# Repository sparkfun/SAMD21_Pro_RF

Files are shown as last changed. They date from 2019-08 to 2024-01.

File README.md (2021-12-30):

SparkFun Pro RF - LoRa, 915MHz (SAMD21)
======================================

SparkFun Pro RF - LoRa, 915MHz (SAMD21) (https://www.sparkfun.com/products/14916)

[*SparkFun SAMD21 Pro RF LoRa 915MHz (WRL-14916)*](https://www.sparkfun.com/products/14916)

The [SparkFun SAMD21 Pro RF](https://www.sparkfun.com/products/14916) is the fated meeting of a SAMD21 and a long-range [RFM95W LoRa®-enabled radio](https://cdn.sparkfun.com/assets/a/9/6/1/0/RFM95W-V2.0.pdf). The outcome is a compact, blazing fast MCU with excellent point to point data transmission in the 915MHz ISM band with LoRa Capabilities. The SAMD21 Pro RF comes with a LiPo connector, an on-board LiPo charger, and a slide switch to power the board on and off. The board programs over a reinforced Micro-B connector with a slim reset button that fits nicely on the side of the board. We’ve even added our popular [Qwiic](https://www.sparkfun.com/qwiic) connector to the edge of the board making it incredibly easy to add sensors and actuators without the need for solder or a soldering iron!

Repository Contents
-------------------

* **/Hardware** - Eagle design files (.brd, .sch)
* **/Production** - Production panel files (.brd)

Documentation
--------------
* **[Hookup Guide](https://learn.sparkfun.com/tutorials/sparkfun-samd21-pro-rf-hookup-guide)** - Basic hookup guide the SAMD21 Pro RF going over the point to point radio capabilities of the radio module and how to set up and use LoRaWAN. 
* **[Arduino Example Code](https://github.com/sparkfun/Sparkfun_SAMD21_Pro_RF_Arduino_Examples)** - Code for the radio module including point to point and LoRaWAN examples.
* **[SAMD21G18A-AU Datasheet](https://cdn.sparkfun.com/datasheets/Dev/Arduino/Boards/Atmel-42181-SAM-D21_Datasheet.pdf)** - Datasheet for the SAMD21G
* **[HopeRF RFM95W Radio Module](https://cdn.sparkfun.com/assets/a/9/6/1/0/RFM95W-V2.0.pdf)** - Datasheet for the RFM95W radio module.

License Information
-------------------

This product is _**open source**_! 

Please review the LICENSE.md file for license information. 

If you have any questions or concerns on licensing, please contact techsupport@sparkfun.com.

Distributed as-is; no warranty is given.

- Your friends at SparkFun.

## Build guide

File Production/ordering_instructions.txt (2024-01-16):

panel size, 159x107mm
PCB thickness, 0.8mm
number of layers, 2
soldermask color, Red
silkscreen color, White
oz copper, 1oz
finish, HASL lead free
stencils, top+bottom
pcs per panel, 9
min trace width, 0.1524mm / 0.0060in
min drill size, 0.3048mm / 0.0120in

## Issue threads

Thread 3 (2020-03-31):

Problem with reset

johnhulth, 2020-03-31:
I have problem with the reset and on/off button. Running the blink example. After uploading the code it runs fine, but if i push reset or switch off and on, the code will not run... no blinking!

Any ideas why I experience this behavior?

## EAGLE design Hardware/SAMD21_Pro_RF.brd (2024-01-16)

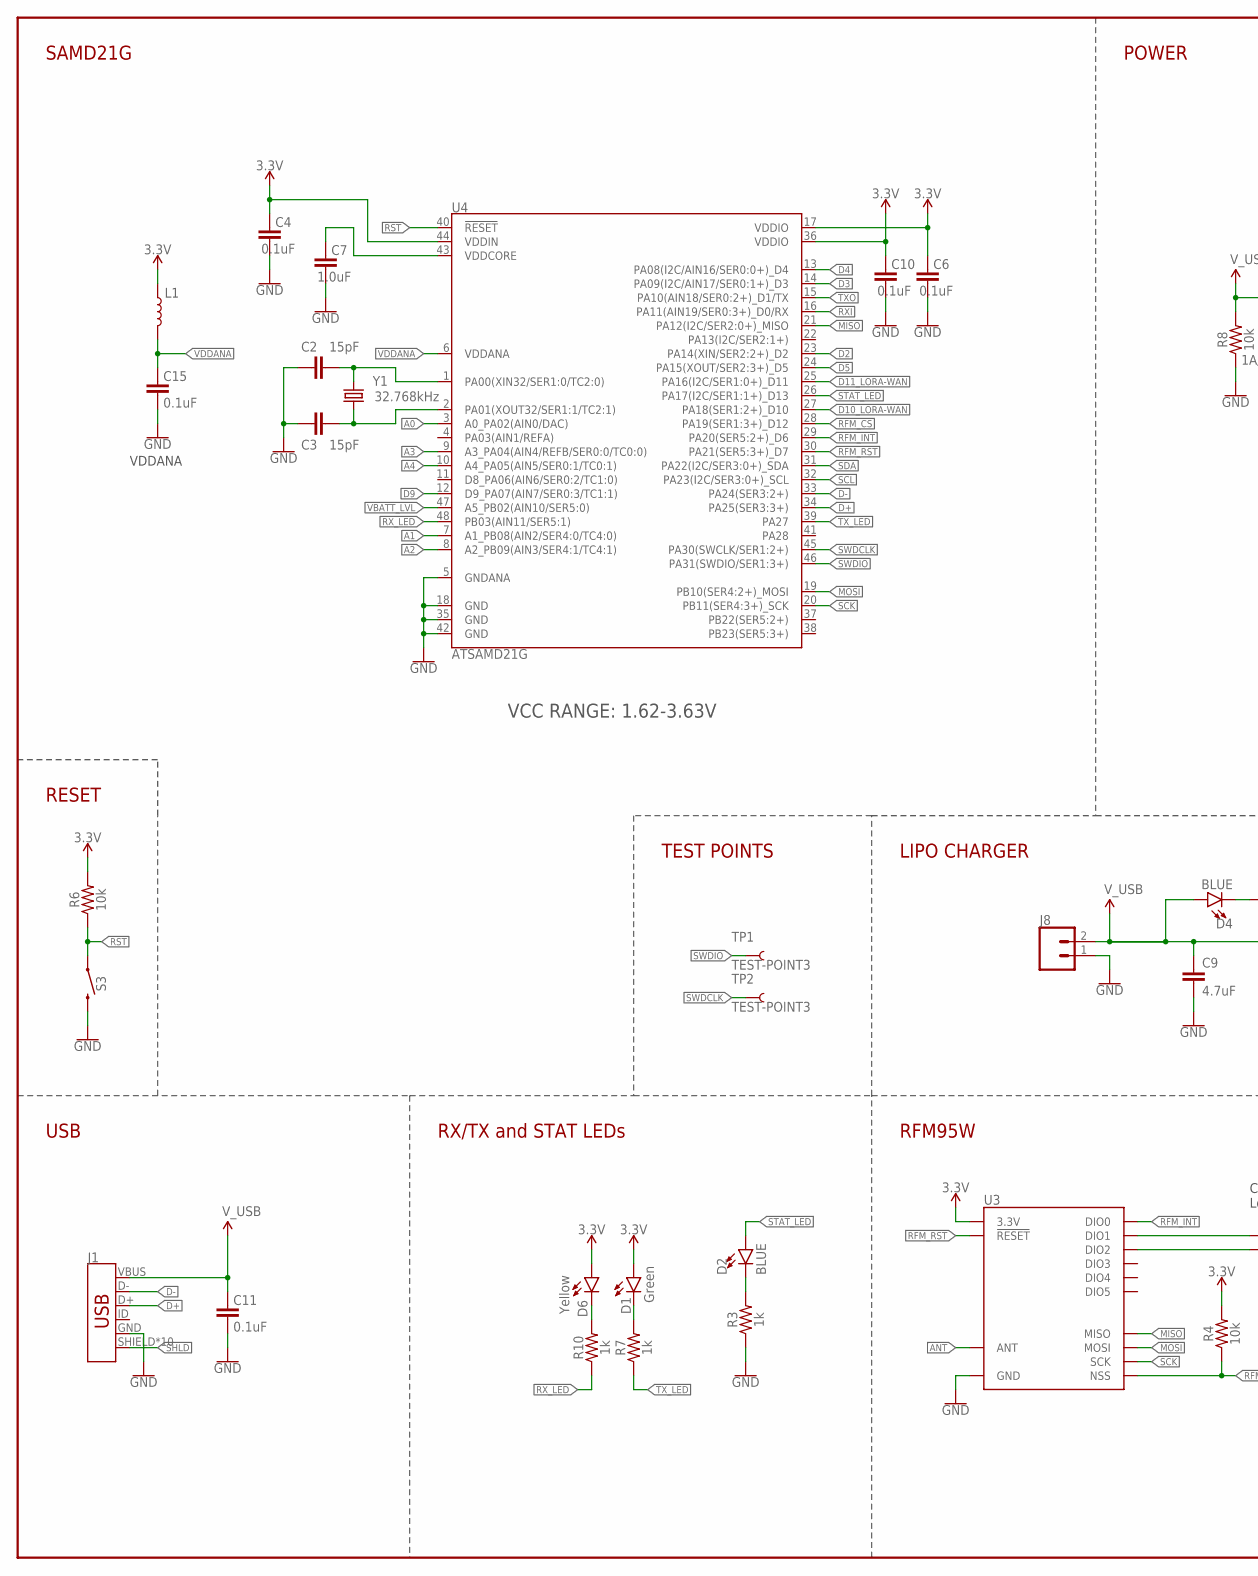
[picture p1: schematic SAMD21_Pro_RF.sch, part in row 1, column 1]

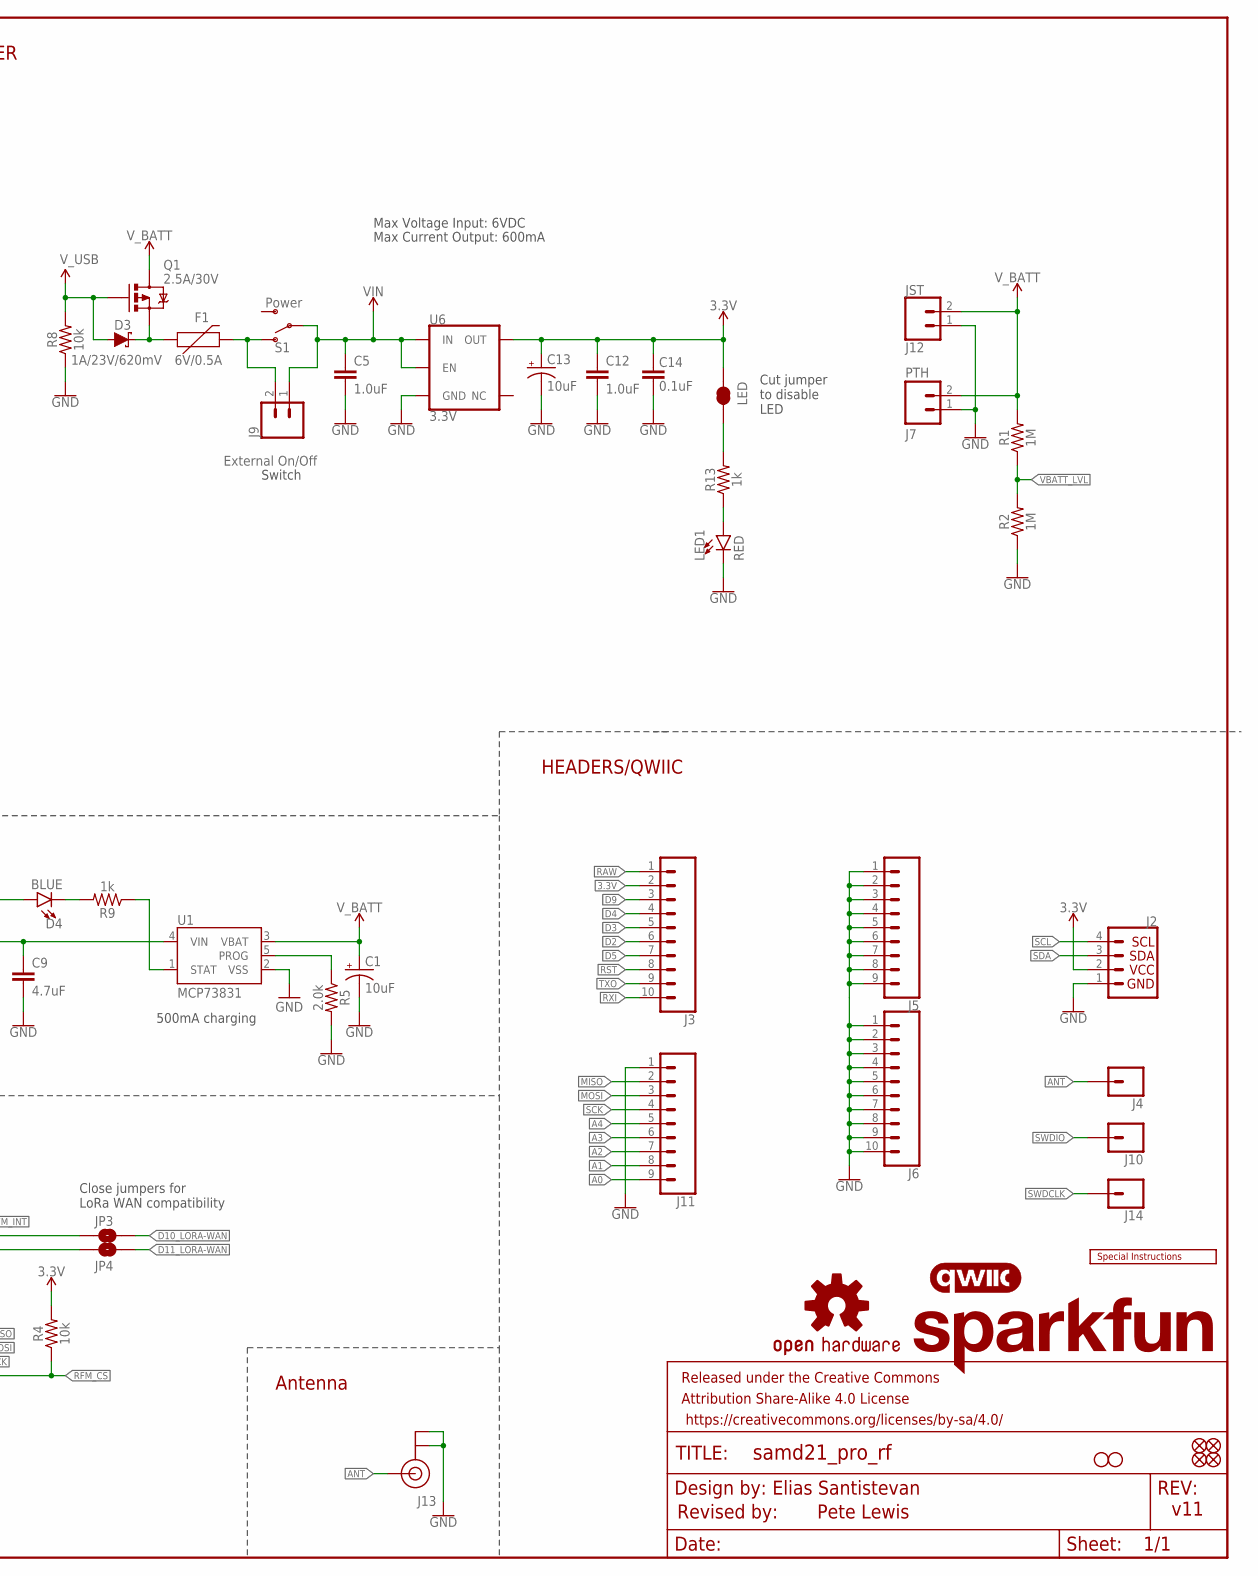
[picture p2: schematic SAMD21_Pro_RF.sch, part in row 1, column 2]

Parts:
C1, C13: 10uF; EIA3216
C2, C3: 15pF; 0603
C4, C6, C10, C11, C14, C15: 0.1uF; 0603
C5, C7, C12: 1.0uF; 0603
C9: 4.7uF; 0603
D1: Green; LED-0603
D2, D4: BLUE; LED-0603
D3: 1A/23V/620mV; SOD-323
D6: Yellow; LED-0603
F1: 6V/0.5A; 1206
FD1, FD2, FD3, FD4: FIDUCIAL1X2; FIDUCIAL-1X2
FRAME2: FRAME-LEDGER; CREATIVE_COMMONS
H1, H2: STAND-OFFTIGHT; STAND-OFF-TIGHT
J1: USB_MICRO-B_HALF_PTH_MILL; USB-MICROB-PTH-MILL
J2: QWIIC_CONNECTORJS-1MM; 1X04_1MM_RA
J3, J6: CONN_10NO_SILK_PTH_FEMALE; 1X10_NO_SILK
J4, J10, J14: CONN_01PTH_NO_SILK_YES_STOP; 1X01_NO_SILK
J5, J11: CONN_09NO_SILK; 1X09_NO_SILK
J7: PTH; 1X02_NO_SILK
J8: CONN_021X02_NO_SILK; 1X02_NO_SILK
J9: External On/Off; 1X02_NO_SILK
J12: JST; JST-2-SMD
J13: U.FL
JP3, JP4: JUMPER-SMT_2_NO_SILK; SMT-JUMPER_2_NO_SILK
L1: INDUCTORFB-30OHM; 0603
LED: JUMPER-SMT_2_NC_TRACE_SILK; SMT-JUMPER_2_NC_TRACE_SILK
LED1: RED; LED-0603
LOGO1: OSHW-LOGOMINI; OSHW-LOGO-MINI
LOGO2: SFE_LOGO_NAME.1_INCH; SFE_LOGO_NAME_.1
LOGO3: QWIIC_LOGO_5MM; QWIIC_5MM
Q1: 2.5A/30V; SOT23-3@1
R1, R2: 1M; 0603
R3, R7, R9, R10, R13: 1k; 0603
R4, R6, R8: 10k; 0603
R5: 2.0k; 0603
S1: Power; SWITCH_SPST_SMD_A
S3: MOMENTARY-SWITCH-SPST-SMD-RIGHT-ANGLE; TACTILE_SWITCH_SMD_RIGHT_ANGLE
TP1, TP2: TEST-POINT3; PAD.03X.03
U1: MCP73831; SOT23-5
U3: RFM95W; RFM95/96/97/98W
U4: ATSAMD21G; QFN-48_NO_EXPOSED_PAD
U6: 3.3V; SOT23-5
U$26: SPECIAL_INSTRUCTIONS-ORDERING; ORDERING_INSTRUCTIONS
Y1: 32.768kHz; CRYSTAL-SMD-3.2X1.5MM

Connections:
3.3V: C4.2, C6.2, C10.2, C12.1, C13.+, C14.2, D1.A, D6.A, J2.2, J3.2, L1.1, LED.1, R4.2, R6.2, U3.3.3V, U4.17 (VDDIO), U4.36 (VDDIO), U4.44 (VDDIN), U6.5 (OUT)
!RFM_CS: R4.1, U3.NSS, U4.28 (PA19(SER1:3+)_D12)
!RFM_RST: U3.!RESET, U4.30 (PA21(SER5:3+)_D7)
!RST: J3.8, R6.1, S3.1, U4.40 (!RESET!)
A0: J11.9, U4.3 (A0_PA02(AIN0/DAC))
A1: J11.8, U4.7 (A1_PB08(AIN2/SER4:0/TC4:0))
A2: J11.7, U4.8 (A2_PB09(AIN3/SER4:1/TC4:1))
A3: J11.6, U4.9 (A3_PA04(AIN4/REFB/SER0:0/TC0:0))
A4: J11.5, U4.10 (A4_PA05(AIN5/SER0:1/TC0:1))
ANT: J4.1, J13.FEED (SIGNAL), U3.ANT
CHARGE_STAT: R9.1, U1.1 (STAT)
D2: J3.6, U4.23 (PA14(XIN/SER2:2+)_D2)
D3: J3.5, U4.14 (PA09(I2C/AIN17/SER0:1+)_D3)
D4: J3.4, U4.13 (PA08(I2C/AIN16/SER0:0+)_D4)
D5: J3.7, U4.24 (PA15(XOUT/SER2:3+)_D5)
D9: J3.3, U4.12 (D9_PA07(AIN7/SER0:3/TC1:1))
D10_LORA-WAN: JP3.2, U4.27 (PA18(SER1:2+)_D10)
D11_LORA-WAN: JP4.2, U4.25 (PA16(I2C/SER1:0+)_D11)
D+: J1.D+, U4.34 (PA25(SER3:3+))
D-: J1.D-, U4.33 (PA24(SER3:2+))
GND: C1.-, C2.1, C3.1, C4.1, C5.2, C6.1, C7.1, C9.2, C10.1, C11.1, C12.2, C13.-, C14.1, C15.1, J1.GND, J2.1, J5.1, J5.2, J5.3, J5.4, J5.5, J5.6, J5.7, J5.8, J5.9, J6.1, J6.2, J6.3, J6.4, J6.5, J6.6, J6.7, J6.8, J6.9, J6.10, J7.1, J8.1, J11.1, J12.1 (2), J13.1 (GND), J13.2 (GND), LED1.C, R2.1, R3.1, R5.2, R8.1, S3.2, U1.2 (VSS), U3.GND@1 (GND), U3.GND@2 (GND), U3.GND@3 (GND), U4.5 (GNDANA), U4.18 (GND), U4.35 (GND), U4.42 (GND), U6.2 (GND)
MISO: J11.2, U3.MISO, U4.21 (PA12(I2C/SER2:0+)_MISO)
MOSI: J11.3, U3.MOSI, U4.19 (PB10(SER4:2+)_MOSI)
unnamed: D6.C, R10.2
unnamed: D1.C, R7.2
unnamed: D2.C, R3.2
unnamed: C7.2, U4.43 (VDDCORE)
unnamed: LED.2, R13.2
unnamed: C2.2, U4.1 (PA00(XIN32/SER1:0/TC2:0)), Y1.P$2 (2)
unnamed: C3.2, U4.2 (PA01(XOUT32/SER1:1/TC2:1)), Y1.P$1 (1)
unnamed: D4.C, R9.2
unnamed: F1.2, J9.2, S1.1 (O)
unnamed: R5.1, U1.5 (PROG)
unnamed: JP3.1, U3.DIO1
unnamed: JP4.1, U3.DIO2
unnamed: LED1.A, R13.1
RAW: D3.C, F1.1, J3.1, Q1.2 (S)
RFM_INT: U3.DIO0, U4.29 (PA20(SER5:2+)_D6)
RXI: J3.10, U4.16 (PA11(AIN19/SER0:3+)_D0/RX)
RX_LED: R10.1, U4.48 (PB03(AIN11/SER5:1))
SCK: J11.4, U3.SCK, U4.20 (PB11(SER4:3+)_SCK)
SCL: J2.4, U4.32 (PA23(I2C/SER3:0+)_SCL)
SDA: J2.3, U4.31 (PA22(I2C/SER3:0+)_SDA)
SHLD: J1.SHIELD, J1.SHIELD2 (SHIELD), J1.SHIELD3 (SHIELD), J1.SHIELD4 (SHIELD), J1.SHIELD5 (SHIELD), J1.SHIELD6 (SHIELD), J1.SHIELD7 (SHIELD), J1.SHIELD8 (SHIELD), J1.SHIELD9 (SHIELD), J1.SHIELD10 (SHIELD)
STAT_LED: D2.A, U4.26 (PA17(I2C/SER1:1+)_D13)
SWDCLK: J14.1, TP2.P$1, U4.45 (PA30(SWCLK/SER1:2+))
SWDIO: J10.1, TP1.P$1, U4.46 (PA31(SWDIO/SER1:3+))
TXO: J3.9, U4.15 (PA10(AIN18/SER0:2+)_D1/TX)
TX_LED: R7.1, U4.39 (PA27)
VBATT_LVL: R1.1, R2.2, U4.47 (A5_PB02(AIN10/SER5:0))
VDDANA: C15.2, L1.2, U4.6 (VDDANA)
VIN: C5.1, J9.1, S1.2, U6.1 (IN), U6.3 (EN)
V_BATT: C1.+, J7.2, J12.2 (1), Q1.3 (D), R1.2, U1.3 (VBAT)
V_USB: C9.1, C11.2, D3.A, D4.A, J1.VBUS, J8.2, Q1.1 (G), R8.2, U1.4 (VIN)

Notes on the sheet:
Max Voltage Input: 6VDC
Max Current Output: 600mA
500mA charging
Close jumpers for LoRa WAN compatibility
VDDANA
SAMD21G
Elias Santistevan
v11
POWER
LIPO CHARGER
RFM95W
RESET
HEADERS/QWIIC
USB
TEST POINTS
Antenna
RX/TX and STAT LEDs
Switch
Revised by:
Pete Lewis
Cut jumper to disable LED
VCC RANGE: 1.62-3.63V

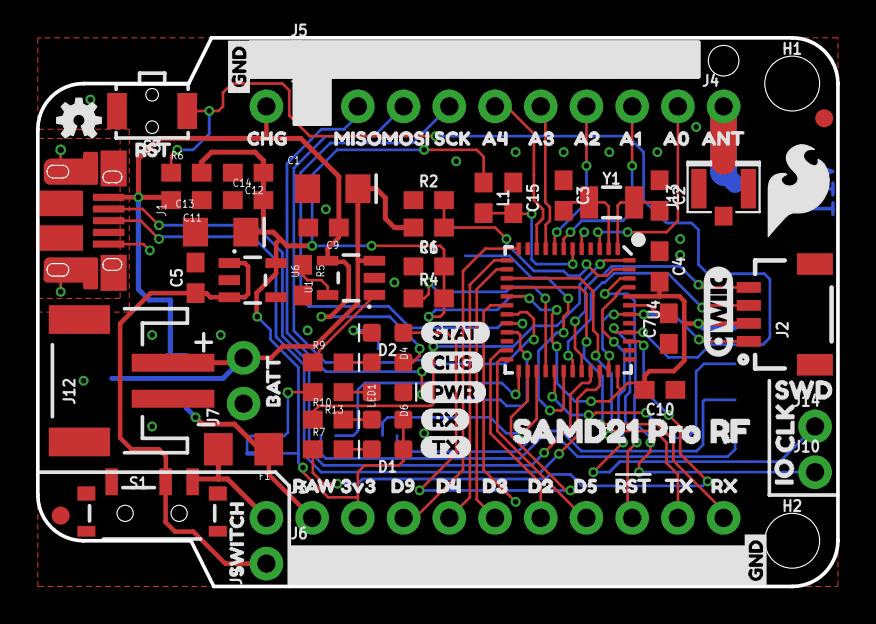
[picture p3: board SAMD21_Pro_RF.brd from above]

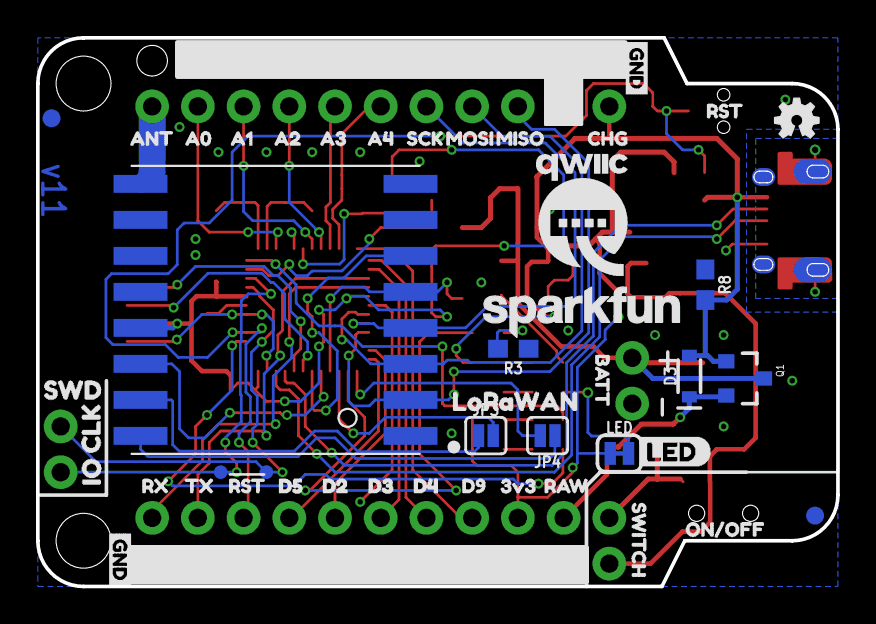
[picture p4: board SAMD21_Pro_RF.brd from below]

Board: 2 copper layers, 44.5 x 30.5 mm, 140 parts (47 on the bottom side), 54 nets.

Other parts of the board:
U$1: SAMD21_PRO_RF0
U$2, U$18: D20
U$3, U$42: A43
U$4, U$43: A34
U$5, U$44: A25
U$6, U$45: A16
U$7, U$46: A07
U$8, U$47: MISO8
U$9, U$48: MOSI9
U$10, U$49: SCK10
U$11, U$50: ANT11
U$12, U$17, U$38, U$62: GND0
U$13, U$28, U$36, U$41: RST2
U$14, U$40, U$65: CHG1
U$15, U$16: D90
U$19, U$73: RX2
U$20, U$21: D30
U$22, U$31: D40
U$23, U$53: 3V320
U$24, U$52: RAW21
U$25: LORA0
U$27, U$37: SWITCH23
U$29, U$32: BATT25
U$30: QWIIC-LOGO-MEDIUM
U$33: D50
U$34, U$64: IO3
U$35: WAN1
U$39: ON#OFF0
U$51: SFE_LOGO_FLAME_.2
U$54: STAT0
U$55: D514
U$56, U$60: CLK4
U$57, U$69: TX3
U$58, U$59: SWD2
U$61: OSHW-LOGO-MINI
U$63: PWR-()-03
U$66: LED0
U$70: TX6
U$72: RX7

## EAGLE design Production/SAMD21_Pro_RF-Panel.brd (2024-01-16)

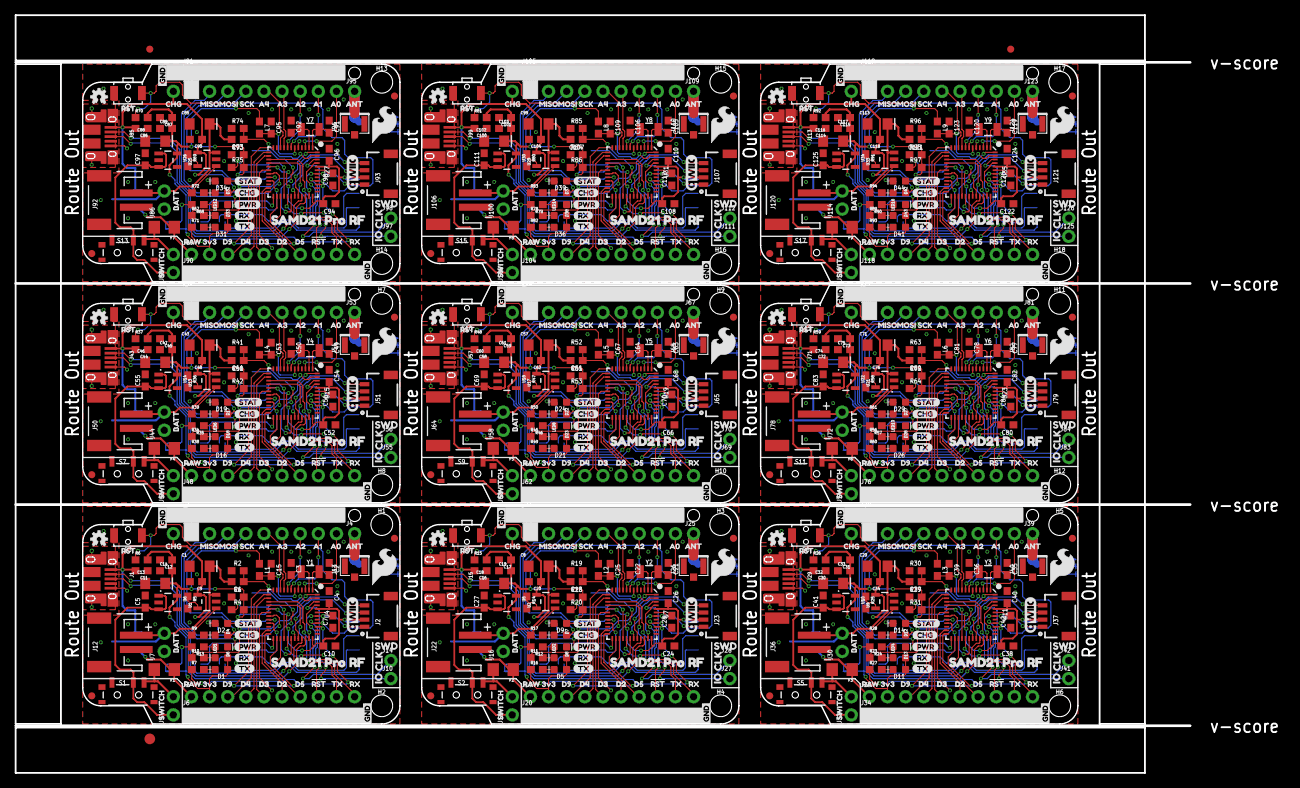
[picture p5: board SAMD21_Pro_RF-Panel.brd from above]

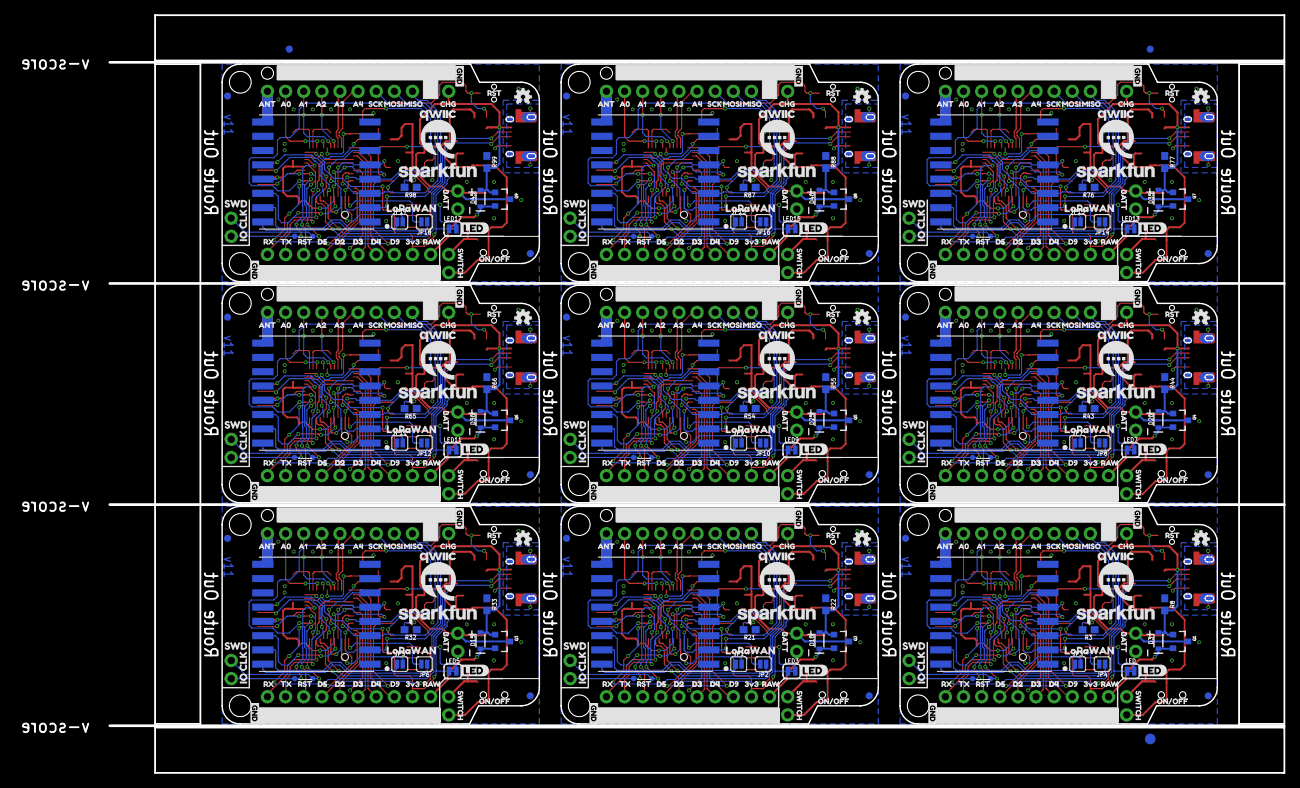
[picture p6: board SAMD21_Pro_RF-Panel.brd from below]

Board: 2 copper layers, 164.6 x 106.2 mm, 1248 parts (426 on the bottom side), 486 nets.

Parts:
C1, C8, C13, C18, C29, C32, C43, C46, C57, C60, C71, C74, C85, C88, C99, C102, C113, C116: 10uF; EIA3216
C2, C3, C21, C22, C35, C36, C49, C50, C63, C64, C77, C78, C91, C92, C105, C106, C119, C120: 15pF; 0603
C4, C6, C10, C11, C14, C15, C16, C19, C23, C24, C25, C26, C30, C33, C37, C38, C39, C40, C44, C47, C51, C52, C53, C54, C58, C61, C65, C66, C67, C68, C72, C75, C79, C80, C81, C82, C86, C89, C93, C94, C95, C96, C100, C103, C107, C108, C109, C110, C114, C117, C121, C122, C123, C124: 0.1uF; 0603
C5, C7, C12, C17, C27, C28, C31, C41, C42, C45, C55, C56, C59, C69, C70, C73, C83, C84, C87, C97, C98, C101, C111, C112, C115, C125, C126: 1.0uF; 0603
C9, C20, C34, C48, C62, C76, C90, C104, C118: 4.7uF; 0603
D1, D5, D11, D16, D21, D26, D31, D36, D41: Green; LED-0603
D2, D4, D7, D9, D12, D14, D17, D19, D22, D24, D27, D29, D32, D34, D37, D39, D42, D44: BLUE; LED-0603
D3, D10, D15, D20, D25, D30, D35, D40, D45: 1A/23V/620mV; SOD-323
D6, D8, D13, D18, D23, D28, D33, D38, D43: Yellow; LED-0603
E$1, E$2, E$3, E$4: FIDUCIAL-1X2
E$5, E$6: FIDUCIAL-1.5X3
F1, F2, F3, F4, F5, F6, F7, F8, F9: 6V/0.5A; 1206
FD1, FD2, FD3, FD4, FD5, FD6, FD7, FD8, FD9, FD10, FD11, FD12, FD13, FD14, FD15, FD16, FD17, FD18, FD19, FD20, FD21, FD22, FD23, FD24, FD25, FD26, FD27, FD28, FD29, FD30, FD31, FD32, FD33, FD34, FD35, FD36: FIDUCIAL1X2; FIDUCIAL-1X2
H1, H2, H3, H4, H5, H6, H7, H8, H9, H10, H11, H12, H13, H14, H15, H16, H17, H18: STAND-OFFTIGHT; STAND-OFF-TIGHT
J1, J15, J29, J43, J57, J71, J85, J99, J113: USB-MICROB-PTH-MILL
J2, J23, J37, J51, J65, J79, J93, J107, J121: 1X04_1MM_RA
J3, J6, J19, J20, J33, J34, J47, J48, J61, J62, J75, J76, J89, J90, J103, J104, J117, J118: 1X10_NO_SILK
J4, J10, J14, J25, J27, J28, J39, J41, J42, J53, J55, J56, J67, J69, J70, J81, J83, J84, J95, J97, J98, J109, J111, J112, J123, J125, J126: 1X01_NO_SILK
J5, J11, J21, J24, J35, J38, J49, J52, J63, J66, J77, J80, J91, J94, J105, J108, J119, J122: 1X09_NO_SILK
J7, J16, J30, J44, J58, J72, J86, J100, J114: PTH; 1X02_NO_SILK
J8, J17, J31, J45, J59, J73, J87, J101, J115: 1X02_NO_SILK
J9, J18, J32, J46, J60, J74, J88, J102, J116: External On/Off; 1X02_NO_SILK
J12, J22, J36, J50, J64, J78, J92, J106, J120: JST; JST-2-SMD
J13, J26, J40, J54, J68, J82, J96, J110, J124: U.FL
JP1, JP2, JP3, JP4, JP5, JP6, JP7, JP8, JP9, JP10, JP11, JP12, JP13, JP14, JP15, JP16, JP17, JP18: SMT-JUMPER_2_NO_SILK
L1, L2, L3, L4, L5, L6, L7, L8, L9: 0603
LED, LED3, LED5, LED7, LED9, LED11, LED13, LED15, LED17: SMT-JUMPER_2_NC_TRACE_SILK
LED1, LED2, LED4, LED6, LED8, LED10, LED12, LED14, LED16: RED; LED-0603
LOGO1, LOGO4, LOGO7, LOGO10, LOGO13, LOGO16, LOGO19, LOGO22, LOGO25: OSHW-LOGOMINI; OSHW-LOGO-MINI
LOGO2, LOGO5, LOGO8, LOGO11, LOGO14, LOGO17, LOGO20, LOGO23, LOGO26: SFE_LOGO_NAME.1_INCH; SFE_LOGO_NAME_.1
LOGO3, LOGO6, LOGO9, LOGO12, LOGO15, LOGO18, LOGO21, LOGO24, LOGO27: QWIIC_LOGO_5MM; QWIIC_5MM
Q1, Q2, Q3, Q4, Q5, Q6, Q7, Q8, Q9: 2.5A/30V; SOT23-3@1
R1, R2, R18, R19, R29, R30, R40, R41, R51, R52, R62, R63, R73, R74, R84, R85, R95, R96: 1M; 0603
R3, R7, R9, R10, R11, R12, R13, R16, R17, R21, R23, R24, R27, R28, R32, R34, R35, R38, R39, R43, R45, R46, R49, R50, R54, R56, R57, R60, R61, R65, R67, R68, R71, R72, R76, R78, R79, R82, R83, R87, R89, R90, R93, R94, R98: 1k; 0603
R4, R6, R8, R15, R20, R22, R26, R31, R33, R37, R42, R44, R48, R53, R55, R59, R64, R66, R70, R75, R77, R81, R86, R88, R92, R97, R99: 10k; 0603
R5, R14, R25, R36, R47, R58, R69, R80, R91: 2.0k; 0603
S1, S2, S5, S7, S9, S11, S13, S15, S17: Power; SWITCH_SPST_SMD_A
S3, S4, S6, S8, S10, S12, S14, S16, S18: TACTILE_SWITCH_SMD_RIGHT_ANGLE
TP1, TP2, TP3, TP4, TP5, TP6, TP7, TP8, TP9, TP10, TP11, TP12, TP13, TP14, TP15, TP16, TP17, TP18: TEST-POINT3; PAD.03X.03
U1, U2, U9, U13, U17, U21, U25, U29, U33: MCP73831; SOT23-5
U3, U8, U12, U16, U20, U24, U28, U32, U36: RFM95W; RFM95/96/97/98W
U4, U7, U11, U15, U19, U23, U27, U31, U35: ATSAMD21G; QFN-48_NO_EXPOSED_PAD
U5, U6, U10, U14, U18, U22, U26, U30, U34: 3.3V; SOT23-5
U$1, U$120, U$189, U$258, U$327, U$396, U$465, U$534, U$603: SAMD21_PRO_RF0
U$2, U$18, U$121, U$125, U$190, U$194, U$259, U$263, U$328, U$332, U$397, U$401, U$466, U$470, U$535, U$539, U$604, U$608: D20
U$3, U$26, U$42, U$94, U$139, U$163, U$208, U$232, U$277, U$301, U$346, U$370, U$415, U$439, U$484, U$508, U$553, U$577: A43
U$4, U$43, U$67, U$95, U$140, U$164, U$209, U$233, U$278, U$302, U$347, U$371, U$416, U$440, U$485, U$509, U$554, U$578: A34
U$5, U$44, U$68, U$96, U$141, U$165, U$210, U$234, U$279, U$303, U$348, U$372, U$417, U$441, U$486, U$510, U$555, U$579: A25
U$6, U$45, U$71, U$97, U$142, U$166, U$211, U$235, U$280, U$304, U$349, U$373, U$418, U$442, U$487, U$511, U$556, U$580: A16
U$7, U$46, U$74, U$98, U$143, U$167, U$212, U$236, U$281, U$305, U$350, U$374, U$419, U$443, U$488, U$512, U$557, U$581: A07
U$8, U$47, U$75, U$99, U$144, U$168, U$213, U$237, U$282, U$306, U$351, U$375, U$420, U$444, U$489, U$513, U$558, U$582: MISO8
U$9, U$48, U$76, U$100, U$145, U$169, U$214, U$238, U$283, U$307, U$352, U$376, U$421, U$445, U$490, U$514, U$559, U$583: MOSI9
U$10, U$49, U$77, U$101, U$146, U$170, U$215, U$239, U$284, U$308, U$353, U$377, U$422, U$446, U$491, U$515, U$560, U$584: SCK10
U$11, U$50, U$78, U$102, U$147, U$171, U$216, U$240, U$285, U$309, U$354, U$378, U$423, U$447, U$492, U$516, U$561, U$585: ANT11
U$12, U$17, U$38, U$62, U$79, U$90, U$105, U$115, U$148, U$159, U$174, U$184, U$217, U$228, U$243, U$253, U$286, U$297, U$312, U$322, U$355, U$366, U$381, U$391, U$424, U$435, U$450, U$460, U$493, U$504, U$519, U$529, U$562, U$573, U$588, U$598: GND0
U$13, U$28, U$36, U$41, U$80, U$85, U$88, U$93, U$149, U$154, U$157, U$162, U$218, U$223, U$226, U$231, U$287, U$292, U$295, U$300, U$356, U$361, U$364, U$369, U$425, U$430, U$433, U$438, U$494, U$499, U$502, U$507, U$563, U$568, U$571, U$576: RST2
U$14, U$40, U$65, U$81, U$92, U$111, U$150, U$161, U$180, U$219, U$230, U$249, U$288, U$299, U$318, U$357, U$368, U$387, U$426, U$437, U$456, U$495, U$506, U$525, U$564, U$575, U$594: CHG1
U$15, U$16, U$113, U$114, U$182, U$183, U$251, U$252, U$320, U$321, U$389, U$390, U$458, U$459, U$527, U$528, U$596, U$597: D90
U$19, U$73, U$110, U$116, U$179, U$185, U$248, U$254, U$317, U$323, U$386, U$392, U$455, U$461, U$524, U$530, U$593, U$599: RX2
U$20, U$21, U$122, U$126, U$191, U$195, U$260, U$264, U$329, U$333, U$398, U$402, U$467, U$471, U$536, U$540, U$605, U$609: D30
U$22, U$31, U$123, U$127, U$192, U$196, U$261, U$265, U$330, U$334, U$399, U$403, U$468, U$472, U$537, U$541, U$606, U$610: D40
U$23, U$53, U$82, U$104, U$151, U$173, U$220, U$242, U$289, U$311, U$358, U$380, U$427, U$449, U$496, U$518, U$565, U$587: 3V320
U$24, U$52, U$83, U$103, U$152, U$172, U$221, U$241, U$290, U$310, U$359, U$379, U$428, U$448, U$497, U$517, U$566, U$586: RAW21
U$25, U$118, U$187, U$256, U$325, U$394, U$463, U$532, U$601: LORA0
U$27, U$37, U$84, U$89, U$153, U$158, U$222, U$227, U$291, U$296, U$360, U$365, U$429, U$434, U$498, U$503, U$567, U$572: SWITCH23
U$29, U$32, U$86, U$87, U$155, U$156, U$224, U$225, U$293, U$294, U$362, U$363, U$431, U$432, U$500, U$501, U$569, U$570: BATT25
U$30, U$128, U$197, U$266, U$335, U$404, U$473, U$542, U$611: QWIIC-LOGO-MEDIUM
U$33, U$124, U$193, U$262, U$331, U$400, U$469, U$538, U$607: D50
U$34, U$64, U$132, U$137, U$201, U$206, U$270, U$275, U$339, U$344, U$408, U$413, U$477, U$482, U$546, U$551, U$615, U$620: IO3
U$35, U$119, U$188, U$257, U$326, U$395, U$464, U$533, U$602: WAN1
U$39, U$91, U$160, U$229, U$298, U$367, U$436, U$505, U$574: ON#OFF0
U$51, U$131, U$200, U$269, U$338, U$407, U$476, U$545, U$614: SFE_LOGO_FLAME_.2
U$54, U$130, U$199, U$268, U$337, U$406, U$475, U$544, U$613: STAT0
U$55, U$112, U$181, U$250, U$319, U$388, U$457, U$526, U$595: D514
U$56, U$60, U$133, U$136, U$202, U$205, U$271, U$274, U$340, U$343, U$409, U$412, U$478, U$481, U$547, U$550, U$616, U$619: CLK4
U$57, U$69, U$107, U$117, U$176, U$186, U$245, U$255, U$314, U$324, U$383, U$393, U$452, U$462, U$521, U$531, U$590, U$600: TX3
U$58, U$59, U$134, U$135, U$203, U$204, U$272, U$273, U$341, U$342, U$410, U$411, U$479, U$480, U$548, U$549, U$617, U$618: SWD2
U$61, U$129, U$198, U$267, U$336, U$405, U$474, U$543, U$612: OSHW-LOGO-MINI
U$63, U$106, U$175, U$244, U$313, U$382, U$451, U$520, U$589: PWR-()-03
U$66, U$138, U$207, U$276, U$345, U$414, U$483, U$552, U$621: LED0
U$70, U$108, U$177, U$246, U$315, U$384, U$453, U$522, U$591: TX6
U$72, U$109, U$178, U$247, U$316, U$385, U$454, U$523, U$592: RX7
Y1, Y2, Y3, Y4, Y5, Y6, Y7, Y8, Y9: 32.768kHz; CRYSTAL-SMD-3.2X1.5MM

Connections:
3.3V: C4.2, C6.2, C10.2, C12.1, C13.+, C14.2, D1.A, D6.A, J2.2, J3.2, L1.1, LED.1, R4.2, R6.2, U3.3.3V, U4.17, U4.36, U4.44, U6.5
3.3V1: C17.1, C18.+, C19.2, C23.2, C24.2, C26.2, D5.A, D8.A, J19.2, J23.2, L2.1, LED3.1, R15.2, R20.2, U5.5, U7.17, U7.36, U7.44, U8.3.3V
3.3V2: C31.1, C32.+, C33.2, C37.2, C38.2, C40.2, D11.A, D13.A, J33.2, J37.2, L3.1, LED5.1, R26.2, R31.2, U10.5, U11.17, U11.36, U11.44, U12.3.3V
3.3V3: C45.1, C46.+, C47.2, C51.2, C52.2, C54.2, D16.A, D18.A, J47.2, J51.2, L4.1, LED7.1, R37.2, R42.2, U14.5, U15.17, U15.36, U15.44, U16.3.3V
3.3V4: C59.1, C60.+, C61.2, C65.2, C66.2, C68.2, D21.A, D23.A, J61.2, J65.2, L5.1, LED9.1, R48.2, R53.2, U18.5, U19.17, U19.36, U19.44, U20.3.3V
3.3V5: C73.1, C74.+, C75.2, C79.2, C80.2, C82.2, D26.A, D28.A, J75.2, J79.2, L6.1, LED11.1, R59.2, R64.2, U22.5, U23.17, U23.36, U23.44, U24.3.3V
3.3V6: C87.1, C88.+, C89.2, C93.2, C94.2, C96.2, D31.A, D33.A, J89.2, J93.2, L7.1, LED13.1, R70.2, R75.2, U26.5, U27.17, U27.36, U27.44, U28.3.3V
3.3V7: C101.1, C102.+, C103.2, C107.2, C108.2, C110.2, D36.A, D38.A, J103.2, J107.2, L8.1, LED15.1, R81.2, R86.2, U30.5, U31.17, U31.36, U31.44, U32.3.3V
3.3V8: C115.1, C116.+, C117.2, C121.2, C122.2, C124.2, D41.A, D43.A, J117.2, J121.2, L9.1, LED17.1, R92.2, R97.2, U34.5, U35.17, U35.36, U35.44, U36.3.3V
!RFM_CS: R4.1, U3.NSS, U4.28
!RFM_CS1: R20.1, U7.28, U8.NSS
!RFM_CS2: R31.1, U11.28, U12.NSS
!RFM_CS3: R42.1, U15.28, U16.NSS
!RFM_CS4: R53.1, U19.28, U20.NSS
!RFM_CS5: R64.1, U23.28, U24.NSS
!RFM_CS6: R75.1, U27.28, U28.NSS
!RFM_CS7: R86.1, U31.28, U32.NSS
!RFM_CS8: R97.1, U35.28, U36.NSS
!RFM_RST: U3.!RESET, U4.30
!RFM_RST1: U7.30, U8.!RESET
!RFM_RST2: U11.30, U12.!RESET
!RFM_RST3: U15.30, U16.!RESET
!RFM_RST4: U19.30, U20.!RESET
!RFM_RST5: U23.30, U24.!RESET
!RFM_RST6: U27.30, U28.!RESET
!RFM_RST7: U31.30, U32.!RESET
!RFM_RST8: U35.30, U36.!RESET
!RST: J3.8, R6.1, S3.1, U4.40
!RST1: J19.8, R15.1, S4.1, U7.40
!RST2: J33.8, R26.1, S6.1, U11.40
!RST3: J47.8, R37.1, S8.1, U15.40
!RST4: J61.8, R48.1, S10.1, U19.40
!RST5: J75.8, R59.1, S12.1, U23.40
!RST6: J89.8, R70.1, S14.1, U27.40
!RST7: J103.8, R81.1, S16.1, U31.40
!RST8: J117.8, R92.1, S18.1, U35.40
A0: J11.9, U4.3
A1: J11.8, U4.7
A2: J11.7, U4.8
A3: J11.6, U4.9
A4: J11.5, U4.10
A5: J24.9, U7.3
A6: J24.8, U7.7
A7: J24.7, U7.8
A8: J24.6, U7.9
A9: J24.5, U7.10
A10: J38.9, U11.3
A11: J38.8, U11.7
A12: J38.7, U11.8
A13: J38.6, U11.9
A14: J38.5, U11.10
A15: J52.9, U15.3
A16: J52.8, U15.7
A17: J52.7, U15.8
A18: J52.6, U15.9
A19: J52.5, U15.10
A20: J66.9, U19.3
A21: J66.8, U19.7
A22: J66.7, U19.8
A23: J66.6, U19.9
A24: J66.5, U19.10
A25: J80.9, U23.3
A26: J80.8, U23.7
A27: J80.7, U23.8
A28: J80.6, U23.9
A29: J80.5, U23.10
A30: J94.9, U27.3
A31: J94.8, U27.7
A32: J94.7, U27.8
A33: J94.6, U27.9
A34: J94.5, U27.10
A35: J108.9, U31.3
A36: J108.8, U31.7
A37: J108.7, U31.8
A38: J108.6, U31.9
A39: J108.5, U31.10
A40: J122.9, U35.3
A41: J122.8, U35.7
A42: J122.7, U35.8
A43: J122.6, U35.9
A44: J122.5, U35.10
ANT: J4.1, J13.FEED, U3.ANT
ANT1: J25.1, J26.FEED, U8.ANT
ANT2: J39.1, J40.FEED, U12.ANT
ANT3: J53.1, J54.FEED, U16.ANT
ANT4: J67.1, J68.FEED, U20.ANT
ANT5: J81.1, J82.FEED, U24.ANT
ANT6: J95.1, J96.FEED, U28.ANT
ANT7: J109.1, J110.FEED, U32.ANT
ANT8: J123.1, J124.FEED, U36.ANT
CHARGE_STAT: R9.1, U1.1
CHARGE_STAT1: R17.1, U2.1
CHARGE_STAT2: R28.1, U9.1
CHARGE_STAT3: R39.1, U13.1
CHARGE_STAT4: R50.1, U17.1
CHARGE_STAT5: R61.1, U21.1
CHARGE_STAT6: R72.1, U25.1
CHARGE_STAT7: R83.1, U29.1
CHARGE_STAT8: R94.1, U33.1
D1: J19.4, U7.13
D2: J3.6, U4.23
D3: J3.5, U4.14
D4: J3.4, U4.13
D5: J3.7, U4.24
D6: J19.6, U7.23
D7: J19.5, U7.14
D8: J19.7, U7.24
D9: J3.3, U4.12
D10: J19.3, U7.12
D10_LORA-WAN: JP3.2, U4.27
D10_LORA-WAN1: JP1.2, U7.27
D10_LORA-WAN2: JP5.2, U11.27
D10_LORA-WAN3: JP7.2, U15.27
D10_LORA-WAN4: JP9.2, U19.27
D10_LORA-WAN5: JP11.2, U23.27
D10_LORA-WAN6: JP13.2, U27.27
D10_LORA-WAN7: JP15.2, U31.27
D10_LORA-WAN8: JP17.2, U35.27
D11: J33.4, U11.13
D11_LORA-WAN: JP4.2, U4.25
D11_LORA-WAN1: JP2.2, U7.25
D11_LORA-WAN2: JP6.2, U11.25
D11_LORA-WAN3: JP8.2, U15.25
D11_LORA-WAN4: JP10.2, U19.25
D11_LORA-WAN5: JP12.2, U23.25
D11_LORA-WAN6: JP14.2, U27.25
D11_LORA-WAN7: JP16.2, U31.25
D11_LORA-WAN8: JP18.2, U35.25
D12: J33.6, U11.23
D13: J33.5, U11.14
D14: J33.7, U11.24
D15: J33.3, U11.12
D16: J47.4, U15.13
D17: J47.6, U15.23
D18: J47.5, U15.14
D19: J47.7, U15.24
D20: J47.3, U15.12
D21: J61.4, U19.13
D22: J61.6, U19.23
D23: J61.5, U19.14
D24: J61.7, U19.24
D25: J61.3, U19.12
D26: J75.4, U23.13
D27: J75.6, U23.23
D28: J75.5, U23.14
D29: J75.7, U23.24
D30: J75.3, U23.12
D31: J89.4, U27.13
D32: J89.6, U27.23
D33: J89.5, U27.14
D34: J89.7, U27.24
D35: J89.3, U27.12
D36: J103.4, U31.13
D37: J103.6, U31.23
D38: J103.5, U31.14
D39: J103.7, U31.24
D40: J103.3, U31.12
D41: J117.4, U35.13
D42: J117.6, U35.23
D43: J117.5, U35.14
D44: J117.7, U35.24
D45: J117.3, U35.12
D+: J1.D+, U4.34
D+1: J15.D+, U7.34
D+2: J29.D+, U11.34
D+3: J43.D+, U15.34
D+4: J57.D+, U19.34
D+5: J71.D+, U23.34
D+6: J85.D+, U27.34
D+7: J99.D+, U31.34
D+8: J113.D+, U35.34
D-: J1.D-, U4.33
D-1: J15.D-, U7.33
D-2: J29.D-, U11.33
D-3: J43.D-, U15.33
D-4: J57.D-, U19.33
D-5: J71.D-, U23.33
D-6: J85.D-, U27.33
D-7: J99.D-, U31.33
D-8: J113.D-, U35.33
GND: C1.-, C2.1, C3.1, C4.1, C5.2, C6.1, C7.1, C9.2, C10.1, C11.1, C12.2, C13.-, C14.1, C15.1, J1.GND, J2.1, J5.1, J5.2, J5.3, J5.4, J5.5, J5.6, J5.7, J5.8, J5.9, J6.1, J6.2, J6.3, J6.4, J6.5, J6.6, J6.7, J6.8, J6.9, J6.10, J7.1, J8.1, J11.1, J12.1, J13.1, J13.2, LED1.C, R2.1, R3.1, R5.2, R8.1, S3.2, U1.2, U3.GND@1, U3.GND@2, U3.GND@3, U4.5, U4.18, U4.35, U4.42, U6.2
GND1: C8.-, C16.1, C17.2, C18.-, C19.1, C20.2, C21.1, C22.1, C23.1, C24.1, C25.1, C26.1, C27.2, C28.1, J15.GND, J16.1, J17.1, J20.1, J20.2, J20.3, J20.4, J20.5, J20.6, J20.7, J20.8, J20.9, J20.10, J21.1, J21.2, J21.3, J21.4, J21.5, J21.6, J21.7, J21.8, J21.9, J22.1, J23.1, J24.1, J26.1, J26.2, LED2.C, R14.2, R19.1, R21.1, R22.1, S4.2, U2.2, U5.2, U7.5, U7.18, U7.35, U7.42, U8.GND@1, U8.GND@2, U8.GND@3
GND2: C29.-, C30.1, C31.2, C32.-, C33.1, C34.2, C35.1, C36.1, C37.1, C38.1, C39.1, C40.1, C41.2, C42.1, J29.GND, J30.1, J31.1, J34.1, J34.2, J34.3, J34.4, J34.5, J34.6, J34.7, J34.8, J34.9, J34.10, J35.1, J35.2, J35.3, J35.4, J35.5, J35.6, J35.7, J35.8, J35.9, J36.1, J37.1, J38.1, J40.1, J40.2, LED4.C, R25.2, R30.1, R32.1, R33.1, S6.2, U9.2, U10.2, U11.5, U11.18, U11.35, U11.42, U12.GND@1, U12.GND@2, U12.GND@3
GND3: C43.-, C44.1, C45.2, C46.-, C47.1, C48.2, C49.1, C50.1, C51.1, C52.1, C53.1, C54.1, C55.2, C56.1, J43.GND, J44.1, J45.1, J48.1, J48.2, J48.3, J48.4, J48.5, J48.6, J48.7, J48.8, J48.9, J48.10, J49.1, J49.2, J49.3, J49.4, J49.5, J49.6, J49.7, J49.8, J49.9, J50.1, J51.1, J52.1, J54.1, J54.2, LED6.C, R36.2, R41.1, R43.1, R44.1, S8.2, U13.2, U14.2, U15.5, U15.18, U15.35, U15.42, U16.GND@1, U16.GND@2, U16.GND@3
GND4: C57.-, C58.1, C59.2, C60.-, C61.1, C62.2, C63.1, C64.1, C65.1, C66.1, C67.1, C68.1, C69.2, C70.1, J57.GND, J58.1, J59.1, J62.1, J62.2, J62.3, J62.4, J62.5, J62.6, J62.7, J62.8, J62.9, J62.10, J63.1, J63.2, J63.3, J63.4, J63.5, J63.6, J63.7, J63.8, J63.9, J64.1, J65.1, J66.1, J68.1, J68.2, LED8.C, R47.2, R52.1, R54.1, R55.1, S10.2, U17.2, U18.2, U19.5, U19.18, U19.35, U19.42, U20.GND@1, U20.GND@2, U20.GND@3
GND5: C71.-, C72.1, C73.2, C74.-, C75.1, C76.2, C77.1, C78.1, C79.1, C80.1, C81.1, C82.1, C83.2, C84.1, J71.GND, J72.1, J73.1, J76.1, J76.2, J76.3, J76.4, J76.5, J76.6, J76.7, J76.8, J76.9, J76.10, J77.1, J77.2, J77.3, J77.4, J77.5, J77.6, J77.7, J77.8, J77.9, J78.1, J79.1, J80.1, J82.1, J82.2, LED10.C, R58.2, R63.1, R65.1, R66.1, S12.2, U21.2, U22.2, U23.5, U23.18, U23.35, U23.42, U24.GND@1, U24.GND@2, U24.GND@3
GND6: C85.-, C86.1, C87.2, C88.-, C89.1, C90.2, C91.1, C92.1, C93.1, C94.1, C95.1, C96.1, C97.2, C98.1, J85.GND, J86.1, J87.1, J90.1, J90.2, J90.3, J90.4, J90.5, J90.6, J90.7, J90.8, J90.9, J90.10, J91.1, J91.2, J91.3, J91.4, J91.5, J91.6, J91.7, J91.8, J91.9, J92.1, J93.1, J94.1, J96.1, J96.2, LED12.C, R69.2, R74.1, R76.1, R77.1, S14.2, U25.2, U26.2, U27.5, U27.18, U27.35, U27.42, U28.GND@1, U28.GND@2, U28.GND@3
GND7: C99.-, C100.1, C101.2, C102.-, C103.1, C104.2, C105.1, C106.1, C107.1, C108.1, C109.1, C110.1, C111.2, C112.1, J99.GND, J100.1, J101.1, J104.1, J104.2, J104.3, J104.4, J104.5, J104.6, J104.7, J104.8, J104.9, J104.10, J105.1, J105.2, J105.3, J105.4, J105.5, J105.6, J105.7, J105.8, J105.9, J106.1, J107.1, J108.1, J110.1, J110.2, LED14.C, R80.2, R85.1, R87.1, R88.1, S16.2, U29.2, U30.2, U31.5, U31.18, U31.35, U31.42, U32.GND@1, U32.GND@2, U32.GND@3
GND8: C113.-, C114.1, C115.2, C116.-, C117.1, C118.2, C119.1, C120.1, C121.1, C122.1, C123.1, C124.1, C125.2, C126.1, J113.GND, J114.1, J115.1, J118.1, J118.2, J118.3, J118.4, J118.5, J118.6, J118.7, J118.8, J118.9, J118.10, J119.1, J119.2, J119.3, J119.4, J119.5, J119.6, J119.7, J119.8, J119.9, J120.1, J121.1, J122.1, J124.1, J124.2, LED16.C, R91.2, R96.1, R98.1, R99.1, S18.2, U33.2, U34.2, U35.5, U35.18, U35.35, U35.42, U36.GND@1, U36.GND@2, U36.GND@3
MISO: J11.2, U3.MISO, U4.21
MISO1: J24.2, U7.21, U8.MISO
MISO2: J38.2, U11.21, U12.MISO
MISO3: J52.2, U15.21, U16.MISO
MISO4: J66.2, U19.21, U20.MISO
MISO5: J80.2, U23.21, U24.MISO
MISO6: J94.2, U27.21, U28.MISO
MISO7: J108.2, U31.21, U32.MISO
MISO8: J122.2, U35.21, U36.MISO
MOSI: J11.3, U3.MOSI, U4.19
MOSI1: J24.3, U7.19, U8.MOSI
MOSI2: J38.3, U11.19, U12.MOSI
MOSI3: J52.3, U15.19, U16.MOSI
MOSI4: J66.3, U19.19, U20.MOSI
MOSI5: J80.3, U23.19, U24.MOSI
MOSI6: J94.3, U27.19, U28.MOSI
MOSI7: J108.3, U31.19, U32.MOSI
MOSI8: J122.3, U35.19, U36.MOSI
unnamed: D6.C, R10.2
unnamed: D1.C, R7.2
unnamed: D2.C, R3.2
unnamed: C7.2, U4.43
unnamed: LED.2, R13.2
unnamed: C2.2, U4.1, Y1.P$2
unnamed: C3.2, U4.2, Y1.P$1
unnamed: D4.C, R9.2
unnamed: F1.2, J9.2, S1.1
unnamed: F2.2, J18.2, S2.1
unnamed: R5.1, U1.5
unnamed: R14.1, U2.5
unnamed: D7.C, R17.2
unnamed: LED2.A, R12.1
unnamed: D8.C, R11.2
unnamed: D5.C, R16.2
unnamed: JP3.1, U3.DIO1
unnamed: JP4.1, U3.DIO2
unnamed: C21.2, U7.1, Y2.P$2
unnamed: C22.2, U7.2, Y2.P$1
unnamed: D9.C, R21.2
unnamed: JP1.1, U8.DIO1
unnamed: JP2.1, U8.DIO2
unnamed: C28.2, U7.43
unnamed: LED3.2, R12.2
unnamed: F3.2, J32.2, S5.1
unnamed: R25.1, U9.5
unnamed: D12.C, R28.2
unnamed: LED4.A, R24.1
unnamed: D13.C, R23.2
unnamed: D11.C, R27.2
unnamed: C35.2, U11.1, Y3.P$2
unnamed: C36.2, U11.2, Y3.P$1
unnamed: D14.C, R32.2
unnamed: JP5.1, U12.DIO1
unnamed: JP6.1, U12.DIO2
unnamed: C42.2, U11.43
unnamed: LED1.A, R13.1
unnamed: LED5.2, R24.2
unnamed: F4.2, J46.2, S7.1
unnamed: R36.1, U13.5
unnamed: D17.C, R39.2
unnamed: LED6.A, R35.1
unnamed: D18.C, R34.2
unnamed: D16.C, R38.2
unnamed: C49.2, U15.1, Y4.P$2
unnamed: C50.2, U15.2, Y4.P$1
unnamed: D19.C, R43.2
unnamed: JP7.1, U16.DIO1
unnamed: JP8.1, U16.DIO2
unnamed: C56.2, U15.43
unnamed: LED7.2, R35.2
unnamed: F5.2, J60.2, S9.1
unnamed: R47.1, U17.5
unnamed: D22.C, R50.2
unnamed: LED8.A, R46.1
unnamed: D23.C, R45.2
unnamed: D21.C, R49.2
unnamed: C63.2, U19.1, Y5.P$2
unnamed: C64.2, U19.2, Y5.P$1
unnamed: D24.C, R54.2
unnamed: JP9.1, U20.DIO1
unnamed: JP10.1, U20.DIO2
unnamed: C70.2, U19.43
unnamed: LED9.2, R46.2
unnamed: F6.2, J74.2, S11.1
unnamed: R58.1, U21.5
unnamed: D27.C, R61.2
unnamed: LED10.A, R57.1
unnamed: D28.C, R56.2
unnamed: D26.C, R60.2
unnamed: C77.2, U23.1, Y6.P$2
unnamed: C78.2, U23.2, Y6.P$1
unnamed: D29.C, R65.2
unnamed: JP11.1, U24.DIO1
unnamed: JP12.1, U24.DIO2
unnamed: C84.2, U23.43
unnamed: LED11.2, R57.2
unnamed: F7.2, J88.2, S13.1
unnamed: R69.1, U25.5
unnamed: D32.C, R72.2
unnamed: LED12.A, R68.1
unnamed: D33.C, R67.2
unnamed: D31.C, R71.2
unnamed: C91.2, U27.1, Y7.P$2
unnamed: C92.2, U27.2, Y7.P$1
unnamed: D34.C, R76.2
unnamed: JP13.1, U28.DIO1
unnamed: JP14.1, U28.DIO2
unnamed: C98.2, U27.43
unnamed: LED13.2, R68.2
unnamed: F8.2, J102.2, S15.1
unnamed: R80.1, U29.5
unnamed: D37.C, R83.2
unnamed: LED14.A, R79.1
unnamed: D38.C, R78.2
unnamed: D36.C, R82.2
unnamed: C105.2, U31.1, Y8.P$2
unnamed: C106.2, U31.2, Y8.P$1
unnamed: D39.C, R87.2
unnamed: JP15.1, U32.DIO1
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

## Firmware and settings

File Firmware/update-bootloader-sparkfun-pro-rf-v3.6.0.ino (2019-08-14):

// Bootloader update sketch. Paste into Arduino IDE and upload to the device
// to update bootloader. It will blink a few times and then start pulsing.
// Your OS will then detect a USB mass storage device.
#include <stdint.h>
const uint8_t bootloader[8192] __attribute__ ((aligned (4))) = {0xd8, 0x2d, 0x00, 0x20, 0x89, 0x02, 0x00, 0x00, 0x85, 0x02, 0x00, 0x00, 0x87, 0x02, 0x00, 0x00,
0x00, 0x00, 0x00, 0x00, 0x00, 0x00, 0x00, 0x00, 0x00, 0x00, 0x00, 0x00, 0x00, 0x00, 0x00, 0x00,
0x00, 0x00, 0x00, 0x00, 0x00, 0x00, 0x00, 0x00, 0x00, 0x00, 0x00, 0x00, 0x85, 0x02, 0x00, 0x00,
0x00, 0x00, 0x00, 0x00, 0x00, 0x00, 0x00, 0x00, 0x85, 0x02, 0x00, 0x00, 0x7d, 0x02, 0x00, 0x00,
0x85, 0x02, 0x00, 0x00, 0x85, 0x02, 0x00, 0x00, 0x85, 0x02, 0x00, 0x00, 0x85, 0x02, 0x00, 0x00,
0x85, 0x02, 0x00, 0x00, 0x85, 0x02, 0x00, 0x00, 0x85, 0x02, 0x00, 0x00, 0x85, 0x02, 0x00, 0x00,
0x85, 0x02, 0x00, 0x00, 0x85, 0x02, 0x00, 0x00, 0x85, 0x02, 0x00, 0x00, 0x85, 0x02, 0x00, 0x00,
0x85, 0x02, 0x00, 0x00, 0x85, 0x02, 0x00, 0x00, 0x85, 0x02, 0x00, 0x00, 0x85, 0x02, 0x00, 0x00,
0x85, 0x02, 0x00, 0x00, 0x85, 0x02, 0x00, 0x00, 0x85, 0x02, 0x00, 0x00, 0x85, 0x02, 0x00, 0x00,
0x85, 0x02, 0x00, 0x00, 0x00, 0x00, 0x00, 0x00, 0x00, 0x00, 0x00, 0x00, 0x85, 0x02, 0x00, 0x00,
0x85, 0x02, 0x00, 0x00, 0x85, 0x02, 0x00, 0x00, 0x85, 0x02, 0x00, 0x00, 0x85, 0x02, 0x00, 0x00,
0x00, 0x00, 0x00, 0x00, 0x07, 0x4b, 0x1a, 0x00, 0x19, 0x7d, 0xc9, 0x07, 0xfc, 0xd5, 0x20, 0x21,
0xff, 0x31, 0x19, 0x83, 0x04, 0x49, 0x40, 0x08, 0xd8, 0x61, 0x19, 0x80, 0x13, 0x7d, 0xdb, 0x07,
0xfc, 0xd5, 0x70, 0x47, 0x00, 0x40, 0x00, 0x41, 0x02, 0xa5, 0xff, 0xff, 0x10, 0xb5, 0x04, 0x00,
0x04, 0x4b, 0x9c, 0x42, 0x00, 0xd9, 0x10, 0xbd, 0x20, 0x00, 0x01, 0x34, 0xff, 0xf7, 0xe2, 0xff,
0xff, 0x34, 0xf5, 0xe7, 0xff, 0xff, 0x03, 0x00, 0x00, 0x23, 0x30, 0xb5, 0x9a, 0x42, 0x00, 0xd1,
0x30, 0xbd, 0x9c, 0x00, 0x0d, 0x59, 0x01, 0x33, 0x05, 0x51, 0xf7, 0xe7, 0xf0, 0xb5, 0x80, 0x25,
0x10, 0x4b, 0x11, 0x4e, 0x5c, 0x68, 0x11, 0x4f, 0xac, 0x43, 0x5c, 0x60, 0x00, 0x2a, 0x00, 0xd1,
0xf0, 0xbd, 0x14, 0x00, 0x10, 0x2a, 0x00, 0xd9, 0x10, 0x24, 0x12, 0x1b, 0x1e, 0x80, 0x1d, 0x7d,
0xed, 0x07, 0xfc, 0xd5, 0xa4, 0x00, 0xa4, 0x46, 0x00, 0x24, 0x0d, 0x59, 0x05, 0x51, 0x04, 0x34,
0x64, 0x45, 0xfa, 0xd1, 0x00, 0x19, 0x09, 0x19, 0x1f, 0x80, 0x1c, 0x7d, 0xe4, 0x07, 0xfc, 0xd5,
0xe4, 0xe7, 0xc0, 0x46, 0x00, 0x40, 0x00, 0x41, 0x44, 0xa5, 0xff, 0xff, 0x04, 0xa5, 0xff, 0xff,
0x80, 0x22, 0x70, 0xb5, 0x00, 0x23, 0x04, 0x00, 0x0d, 0x00, 0x52, 0x00, 0xe9, 0x58, 0xe0, 0x58,
0x81, 0x42, 0x03, 0xd1, 0x04, 0x33, 0x93, 0x42, 0xf8, 0xd1, 0x70, 0xbd, 0x20, 0x00, 0xff, 0xf7,
0x99, 0xff, 0x40, 0x22, 0x29, 0x00, 0x20, 0x00, 0xff, 0xf7, 0xc0, 0xff, 0xf5, 0xe7, 0x00, 0x00,
0x02, 0x4a, 0x53, 0x78, 0x5b, 0xb2, 0x00, 0x2b, 0xfb, 0xdb, 0x70, 0x47, 0x00, 0x0c, 0x00, 0x40,
0x10, 0x23, 0x02, 0x49, 0xca, 0x68, 0x1a, 0x42, 0xfc, 0xd0, 0x70, 0x47, 0x00, 0x08, 0x00, 0x40,
0x1e, 0x21, 0xf8, 0xb5, 0x02, 0x26, 0x25, 0x4a, 0x25, 0x4c, 0x53, 0x68, 0x25, 0x4d, 0x8b, 0x43,
0x33, 0x43, 0x53, 0x60, 0xa6, 0x60, 0xff, 0xf7, 0xe3, 0xff, 0x23, 0x4b, 0x63, 0x60, 0xff, 0xf7,
0xdf, 0xff, 0xae, 0x84, 0xff, 0xf7, 0xe4, 0xff, 0x20, 0x4b, 0x1b, 0x68, 0x9b, 0x0e, 0x3f, 0x2b,
0x00, 0xd1, 0x20, 0x3b, 0x00, 0x26, 0x02, 0x27, 0x1d, 0x4a, 0x9b, 0x02, 0x13, 0x43, 0x1d, 0x4a,
0xea, 0x62, 0xab, 0x62, 0xae, 0x84, 0xff, 0xf7, 0xd3, 0xff, 0x1b, 0x4b, 0xab, 0x84, 0xff, 0xf7,
0xcf, 0xff, 0xab, 0x8c, 0x3b, 0x43, 0xab, 0x84, 0xff, 0xf7, 0xca, 0xff, 0x3f, 0x22, 0x63, 0x88,
0x93, 0x43, 0x80, 0x22, 0x1f, 0x43, 0x67, 0x80, 0x63, 0x88, 0xd2, 0x01, 0x13, 0x43, 0x63, 0x80,
0xa6, 0x60, 0xff, 0xf7, 0xb5, 0xff, 0x11, 0x4b, 0x63, 0x60, 0xff, 0xf7, 0xb1, 0xff, 0xc0, 0x21,
0x0f, 0x4a, 0x10, 0x4b, 0x10, 0x48, 0x53, 0x60, 0x03, 0x6a, 0x09, 0x06, 0x1b, 0x02, 0x1b, 0x0a,
0x0b, 0x43, 0x03, 0x62, 0x07, 0x23, 0x96, 0x60, 0x13, 0x60, 0xf8, 0xbd, 0x00, 0x40, 0x00, 0x41,
0x00, 0x0c, 0x00, 0x40, 0x00, 0x08, 0x00, 0x40, 0x06, 0x00, 0x01, 0x00, 0x24, 0x60, 0x80, 0x00,
0xff, 0x01, 0x00, 0x00, 0x80, 0xbb, 0x0a, 0x1c, 0x24, 0x05, 0x00, 0x00, 0x00, 0x07, 0x03, 0x00,
0x10, 0xe0, 0x00, 0xe0, 0xe7, 0x03, 0x00, 0x00, 0x00, 0xed, 0x00, 0xe0, 0x10, 0xb5, 0x00, 0xf0,
0xf1, 0xf8, 0x10, 0xbd, 0xfe, 0xe7, 0xfe, 0xe7, 0x20, 0x48, 0x21, 0x49, 0x70, 0xb5, 0x00, 0x23,
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

};
const uint16_t bootloader_crcs[] = {0xc65b ,0xc8fa ,0x238d ,0x85f7 ,0xdd30 ,0xd12b ,0xaf17 ,0xd476};
#define BOOTLOADER_K 8

static uint16_t crcCache[256];

#define CRC16POLY 0x1021

#define FLASH_ROW_SIZE (FLASH_PAGE_SIZE * 4)

uint16_t add_crc(uint8_t ch, unsigned short crc0) {
    if (!crcCache[1]) {
        for (int ptr = 0; ptr < 256; ptr++) {
            uint16_t crc = (int)ptr << 8;
            for (uint16_t cmpt = 0; cmpt < 8; cmpt++) {
                if (crc & 0x8000)
                    crc = crc << 1 ^ CRC16POLY;
                else
                    crc = crc << 1;
            }
            crcCache[ptr] = crc;
        }
    }

    return ((crc0 << 8) ^ crcCache[((crc0 >> 8) ^ ch) & 0xff]) & 0xffff;
}

uint8_t pageBuf[FLASH_ROW_SIZE];

#define NVM_USER_MEMORY ((volatile uint16_t *)NVMCTRL_USER)

static inline void wait_ready(void) {
    while (NVMCTRL->INTFLAG.bit.READY == 0) {
    }
}

void flash_erase_row(uint32_t *dst) {
    wait_ready();
    NVMCTRL->STATUS.reg = NVMCTRL_STATUS_MASK;

    // Execute "ER" Erase Row
    NVMCTRL->ADDR.reg = (uint32_t)dst / 2;
    NVMCTRL->CTRLA.reg = NVMCTRL_CTRLA_CMDEX_KEY | NVMCTRL_CTRLA_CMD_ER;
    wait_ready();
}

void flash_write_words(uint32_t *dst, uint32_t *src, uint32_t n_words) {
    // Set automatic page write
    NVMCTRL->CTRLB.bit.MANW = 0;

    while (n_words > 0) {
        uint32_t len = min(FLASH_PAGE_SIZE >> 2, n_words);
        n_words -= len;

        // Execute "PBC" Page Buffer Clear
        NVMCTRL->CTRLA.reg = NVMCTRL_CTRLA_CMDEX_KEY | NVMCTRL_CTRLA_CMD_PBC;
        wait_ready();

        // make sure there are no other memory writes here
        // otherwise we get lock-ups

        while (len--)
            *dst++ = *src++;

        // Execute "WP" Write Page
        NVMCTRL->CTRLA.reg = NVMCTRL_CTRLA_CMDEX_KEY | NVMCTRL_CTRLA_CMD_WP;
        wait_ready();
    }
}

void flash_write_row(uint32_t *dst, uint32_t *src) {
    flash_erase_row(dst);
    flash_write_words(dst, src, FLASH_ROW_SIZE / 4);
}

#define exec_cmd(cmd)                                                                              \
    do {                                                                                           \
        NVMCTRL->STATUS.reg |= NVMCTRL_STATUS_MASK;                                                \
        NVMCTRL->ADDR.reg = (uint32_t)NVMCTRL_USER / 2;                                            \
        NVMCTRL->CTRLA.reg = NVMCTRL_CTRLA_CMDEX_KEY | cmd;                                        \
        while (NVMCTRL->INTFLAG.bit.READY == 0)                                                    \
            ;                                                                                      \
    } while (0)

void setBootProt(int v) {
    uint32_t fuses[2];

    while (!(NVMCTRL->INTFLAG.reg & NVMCTRL_INTFLAG_READY))
        ;

    fuses[0] = *((uint32_t *)NVMCTRL_AUX0_ADDRESS);
    fuses[1] = *(((uint32_t *)NVMCTRL_AUX0_ADDRESS) + 1);

    uint32_t bootprot = (fuses[0] & NVMCTRL_FUSES_BOOTPROT_Msk) >> NVMCTRL_FUSES_BOOTPROT_Pos;

    if (bootprot == v)
        return;

    fuses[0] = (fuses[0] & ~NVMCTRL_FUSES_BOOTPROT_Msk) | (v << NVMCTRL_FUSES_BOOTPROT_Pos);

    NVMCTRL->CTRLB.reg = NVMCTRL->CTRLB.reg | NVMCTRL_CTRLB_CACHEDIS | NVMCTRL_CTRLB_MANW;

    exec_cmd(NVMCTRL_CTRLA_CMD_EAR);
    exec_cmd(NVMCTRL_CTRLA_CMD_PBC);

    *((uint32_t *)NVMCTRL_AUX0_ADDRESS) = fuses[0];
    *(((uint32_t *)NVMCTRL_AUX0_ADDRESS) + 1) = fuses[1];

    exec_cmd(NVMCTRL_CTRLA_CMD_WAP);

    NVIC_SystemReset();
}

void mydelay(int ms) {
    ms <<= 13;
    while (ms--) {
        asm("nop");
    }
}

void setup() {
    pinMode(LED_BUILTIN, OUTPUT);
    digitalWrite(LED_BUILTIN, HIGH);

    if (8 << NVMCTRL->PARAM.bit.PSZ != FLASH_PAGE_SIZE)
        while (1) {
        }

    __disable_irq();

    setBootProt(7); // 0k

    const uint8_t *ptr = bootloader;
    int i;

    for (i = 0; i < BOOTLOADER_K; ++i) {
        int crc = 0;
        for (int j = 0; j < 1024; ++j) {
            crc = add_crc(*ptr++, crc);
        }
        if (bootloader_crcs[i] != crc) {
            while (1) {
            }
        }
    }

    for (i = 0; i < BOOTLOADER_K * 1024; i += FLASH_ROW_SIZE) {
        memcpy(pageBuf, &bootloader[i], FLASH_ROW_SIZE);
        flash_write_row((uint32_t *)(void *)i, (uint32_t *)(void *)pageBuf);
    }

    // re-base int vector back to bootloader, so that the flash erase below doesn't write over the
    // vectors
    SCB->VTOR = 0;

    // erase first row of this updater app, so the bootloader doesn't start us again
    flash_erase_row((uint32_t *)(void *)(BOOTLOADER_K * 1024));

    for (i = 0; i < 5; ++i) {
        digitalWrite(LED_BUILTIN, HIGH);
        mydelay(100);
        digitalWrite(LED_BUILTIN, LOW);
        mydelay(200);
    }

    setBootProt(2); // 8k

    while (1) {
    }
}

void loop() {}

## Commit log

2018-08-16 Added Sparkfun labels, correct RFM module (same pinout), fixed silk
    [SAMD21_Pro_RF.brd, SAMD21_Pro_RF.sch]
2018-08-16 More silk fixes
    [SAMD21_Pro_RF.brd]
2018-08-17 RX/TX LED Spacing
    [SAMD21_Pro_RF.brd]
2018-08-17 Removed Flash, added standoffs
    [SAMD21_Pro_RF.brd, SAMD21_Pro_RF.sch]
2018-08-22 Post Review fixes
    [SAMD21_Pro_RF.brd, SAMD21_Pro_RF.sch]
2018-08-23 Issues caught
    Replaced 10k resistors with 1M Ohm resistors, added Mosfet circuit, moved decoupling capacitors in schematic to more clearly reflect their placement on the board, and removed jumper from RAW line. All power lines have been updated with better labels.
    [SAMD21_Pro_RF.brd, SAMD21_Pro_RF.sch]
2018-09-26 Production Files were inconsitent
    [SAMD21_Pro_RF-Panel.GBL, SAMD21_Pro_RF-Panel.GBO, SAMD21_Pro_RF-Panel.GBP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]
2018-10-01 v10
    Cleanup of repo, updated readme.
    [SAMD21_Pro_RF.brd, SAMD21_Pro_RF.sch]
2018-10-02 These production files doubled up and the incorrect ones.
    [SAMD21_Pro_RF-Panel.GBL, SAMD21_Pro_RF-Panel.GBO, SAMD21_Pro_RF-Panel.GBP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]
2019-10-29 VDDCORE now has 01uF cap to GND
    Previously, it was incorrectly connected to VDDIN (3.3V)
    -bumped version to v11
    -updated gitignore
    -added quiic logo
    [SAMD21_Pro_RF.brd, SAMD21_Pro_RF.sch]
2019-10-29 included PTH headers for SWD lines
    note, I did not move test points.
    [SAMD21_Pro_RF.brd, SAMD21_Pro_RF.sch]
2019-10-29 Added LED disable Jumper NC trace
    for easier access to disable Power LED in low power applications
    [SAMD21_Pro_RF.brd, SAMD21_Pro_RF.sch]
2019-10-30 Changed C7 to 1.0uF as recommended in DS
    This is the VDDCORE cap to GND.
    [SAMD21_Pro_RF.brd, SAMD21_Pro_RF.sch]
2019-10-30 One GND symbol in old library
    [SAMD21_Pro_RF.sch]
2019-10-31 sch stuff
    - removed one extra 3.3V symbol near IC
    - added vcc range to sch near IC
    [SAMD21_Pro_RF.sch]
2023-12-18 Adds correct panel
    [SAMD21_Pro_RF-Panel.GBL, SAMD21_Pro_RF-Panel.GBO, SAMD21_Pro_RF-Panel.GBS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]
2024-01-16 Adds new panel
    [SAMD21_Pro_RF-Panel.GBL, SAMD21_Pro_RF-Panel.GBO, SAMD21_Pro_RF-Panel.GBP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]
2024-01-16 Updated panel fiducials
    [SAMD21_Pro_RF-Panel.brd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]
2024-01-16 Adds more details to ordering instructions
    [SAMD21_Pro_RF.brd, SAMD21_Pro_RF.sch]

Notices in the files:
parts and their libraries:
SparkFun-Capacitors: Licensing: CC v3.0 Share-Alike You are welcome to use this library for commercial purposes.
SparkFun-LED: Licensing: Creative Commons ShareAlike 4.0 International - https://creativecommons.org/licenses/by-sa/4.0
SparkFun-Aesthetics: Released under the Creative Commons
